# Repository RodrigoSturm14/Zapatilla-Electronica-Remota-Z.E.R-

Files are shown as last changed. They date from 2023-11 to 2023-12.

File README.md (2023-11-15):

#  Zapatilla Electrónica Remota (Z.E.R) ⚡🏠
zer_3

# Descripción del proyecto
Este repositorio se dedica a documentar y recopilar el desarrollo de **Z.E.R**; un proyecto de automatizacion IoT desarrollado por Montial Octavio, Pierini Franco, Vallone Fabrizio, Sturm Rodrigo y Zuñiga Juan Jose.

Z.E.R es una zapatilla eléctrica que fue diseñada para activar y desactivar sus tomacorrientes inalámbricamente mediante nuestra aplicación móvil a través del uso de comunicación MQTT.
Decidimos implementar el protocolo de comunicacion MQTT debido a su sensillo uso y accecible conectividad WiFi con el microcontrolador ESP32.
Gracias a este proyecto, ampliamos nuestro conocimiento en diferentes areas como en el **desarrollo de Hardware**, **diseño de PCBs**, **desarrollo de Software (JavaScript - C++)** y **diseño 3D (SolidWork)**.

# Caracteristicas de Z.E.R
* **Microcontrolador ESP32** para hacer posible la conectividad IoT y un alto nivel de procesamiento.
* **Protocolo de comunicación MQTT** para la transmisión de datos a tiempo real.
* **Aplicación móvil** para una interfaz gráfica de usuario sencilla y accesible.
*  **Aprovisionamiento WiFi** para la conexión automática a redes WiFi.
* **Almacenamiento no volátil (NVS)** para guardar información temporalmente en la memoria flash del microcontrolador.
* **Sistema embebido unificado** para mayor ahorro de espacio y material.

#  Estructura del Repositorio
* **/Software**, se hayan las carpetas y los archivos de la programación móvil y del sistema embebido.
* **/Hardware**, se haya los recursos para observar el progreso del diseño del PCB.
* **/Diseño 3D**, se encuentran los archivos .STL  utilizados en el proyecto.

# Archivos Multimedia

## Fotos
### Aplicacion Movil

Aqui se muestra la estructura de la app. En la seccion superior puede verse el nombre del dispositivo, mientras que en el resto de la pantalla se situa la informacion de los diferentes tomas. Se tienen los siguientes elementos para controlar cada uno de los tomacorriente: 

* **Botones de encender y apagar**
* **Tabla indicativa del estado del toma** (Su color y mensaje cambia depende el estado).



### Diagramas de conexion con el broker

En este diagrama se ven las conexiones entre el broker y los nodos de la aplicacion movil y el microcontrolador. El broker MQTT es un intermediario en la comunicacion entre la aplicacion movil y el ESP32. Para que este protocolo funcione, ambas partes deben estar conectadas a una red WiFi.

zer_4

### Interfaz grafica de conexiones en el broker

En esta imagen se ven representadas las conexiones que se realizan al usar el proyecto. El broker [Shiftr](https://www.shiftr.io/) permite ver un diagrama de conexiones a tiempo real de los clientes y los topicos. Por un lado, el "esp32-client" representa al microcontrolador de la zapatilla, el cual se encarga de recibir la informacion enviada por parte de la app. Esta ultima se ve en el otro extremo de la conexion. Por ultimo, se encuentran los "topicos" en donde se almacenan los mensajes enviados desde la app. Estos serian los tomas, y pueden adoptar un mensaje de "encendido" o "apagado".



### Placa Master 

En esta imagen se puede observar la placa principal del proyecto, la cual cumple el rol de recibir y confirmar este recibimiento los datos provenientes del broquer mqtt y encender o no cada uno de los tomas en consecuencia.
Principalmente está conformada por:
* **El microcontrolador Esp32:** Encargado de la comunicación con el broker mqtt y el proceso lógico en consecuencia
* **Los Relay:** Principales responsables del encendido y/o apagado de los tomas del proyecto.

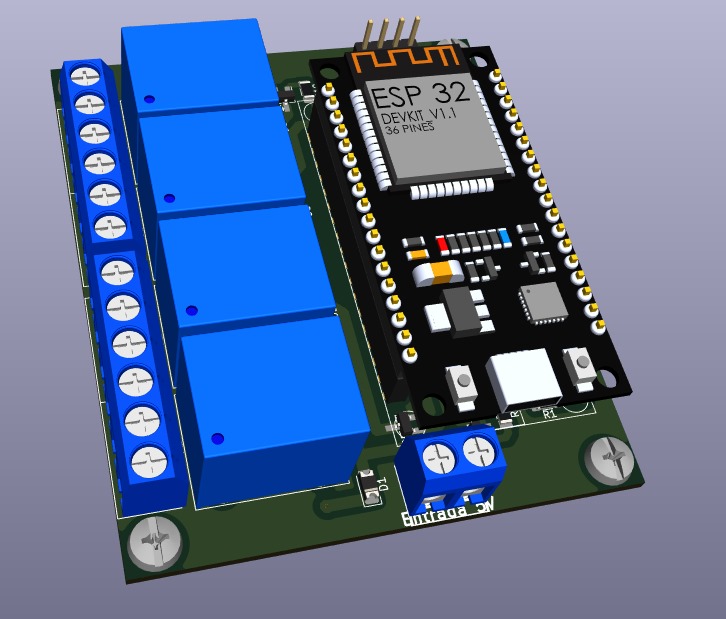
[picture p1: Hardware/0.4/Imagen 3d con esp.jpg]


### Placa de Periféricos:

En esta imagen se puede observar la placa secundaria del proyecto, la cual cumple el rol de mostrarle al usuario de forma visual el estado de conexión del dispositivo y una ruta de fácil acceso para poder reconfigurar este (conectar a una nueva red wifi). 
Principalmente está conformada por:
* **LEDs:** Quienes se encargan de mostrar si el dispositivo está conectado al Wifi, y de ser así, también otro para el caso del broquer mqtt.
* **Pulsador:** Perimite entrar al estado de configuración de Wifi en el caso de que este no pueda conectarse o de cambiar de ubicación el dispositivo.

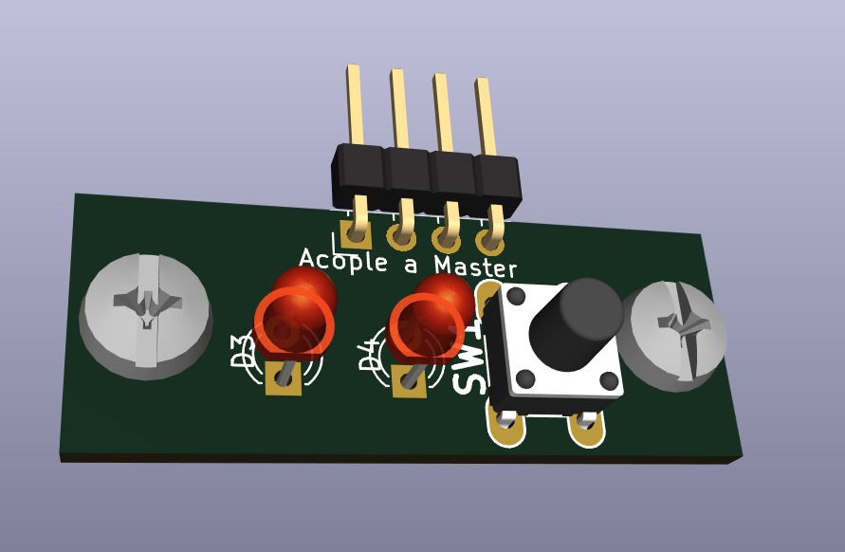
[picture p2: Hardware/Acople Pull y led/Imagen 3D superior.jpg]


## Videos
zer_video_img

[Video](https://drive.google.com/file/d/11wxJRINLuGf1xzWTfpv2VvfbYe2Eymw4/view?usp=sharing)

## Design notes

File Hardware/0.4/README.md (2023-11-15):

# Placa Master

En esta imagen se puede observar la placa principal del proyecto, la cual cumple el rol de recibir y confirmar este recibimiento los datos provenientes del broquer mqtt y encender o no cada uno de los tomas en consecuencia.
Principalmente está conformada por:
* **El microcontrolador Esp32:** Encargado de la comunicación con el broker mqtt y el proceso lógico en consecuencia.
* **Los Relay:** Principales responsables del encendido y/o apagado de los tomas del proyecto.



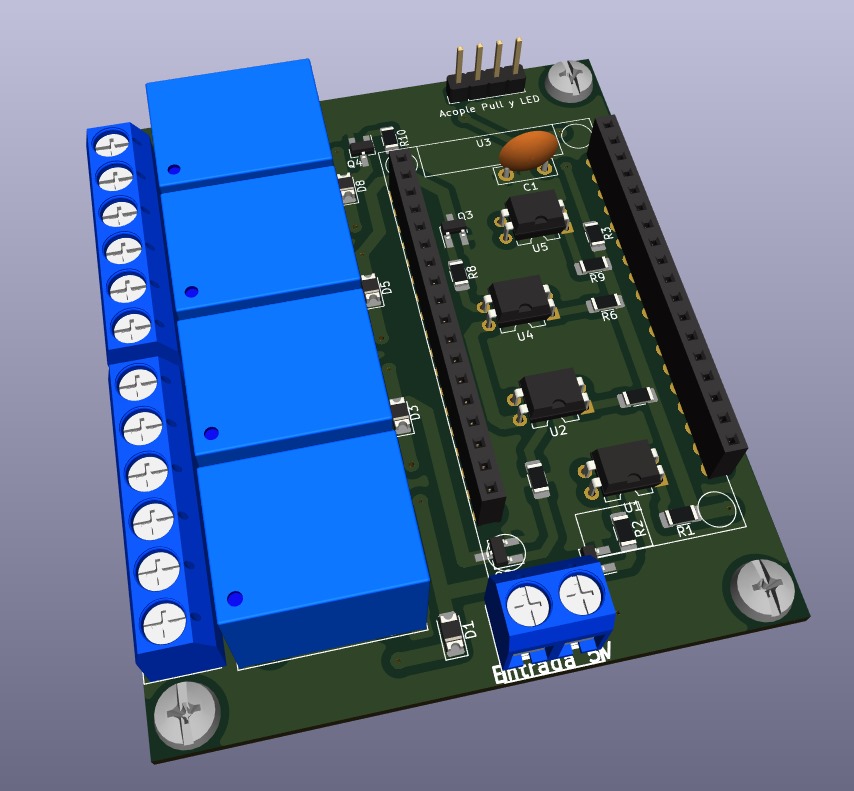
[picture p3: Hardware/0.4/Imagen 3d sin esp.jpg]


## Funcionamiento:

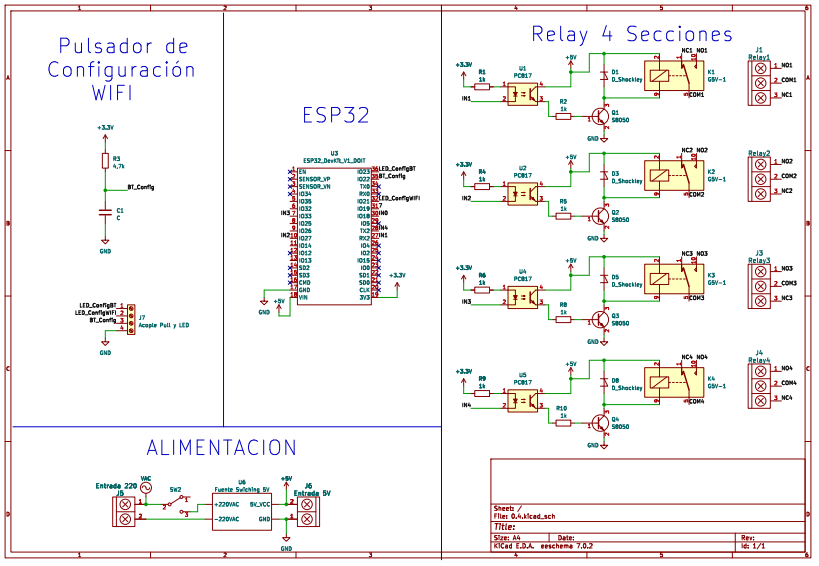
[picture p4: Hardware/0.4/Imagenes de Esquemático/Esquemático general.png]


Como se ve en el esquemático, la placa se separa en 4 partes:

### Esp32:

El cual permite la comunicacíon entre el broker mqtt y el la placa. Siendo el encargado de indicarle al resto de la placa las acciones a realizar.

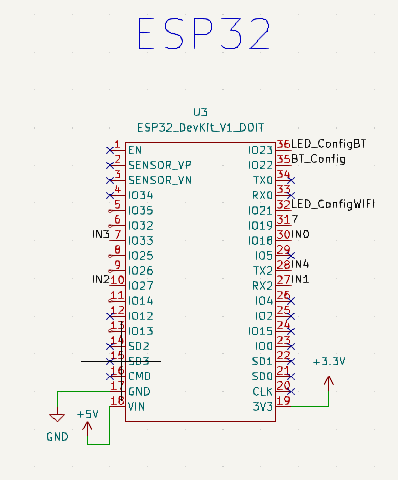
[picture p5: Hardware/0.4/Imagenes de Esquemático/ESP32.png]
esp


### Relay:

Aqui se utiliza la señal generada por el microcontrolador para accionar los relay y encender o apagar cada tomacorriete. 
Para esto se utilizan 2 componentes cruciales:
* **El octoacoplador:** Quien separa las tenciones del microcontrolador de las de actuación del relay.
* **El transistor:** Quien permite accionar el relay utilizando la señal del octoacoblador:

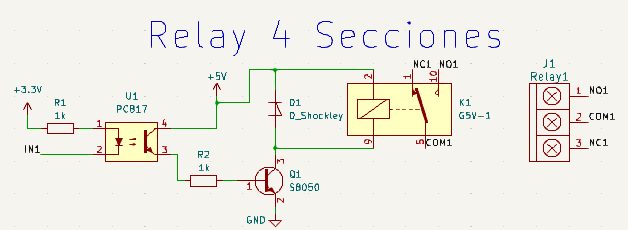
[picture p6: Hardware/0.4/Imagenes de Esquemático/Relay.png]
Relay


### Alimentación:
Aqui se utiliza una fuente switching genérica de 5v 700mA para poder alimentar el proyecto utilizando directamente la red doméstica.

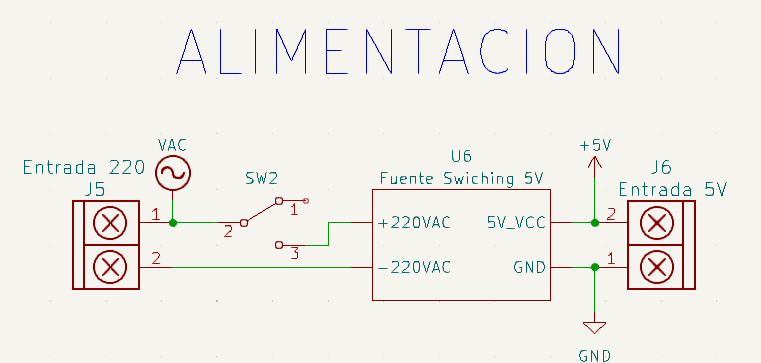
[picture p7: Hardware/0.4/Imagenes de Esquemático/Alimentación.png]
Alimen


### Pulsador de configuracion Wifi:
Aquí se ubica una coneccion la cual permitirá comunicar la placa master con el periferico restante.

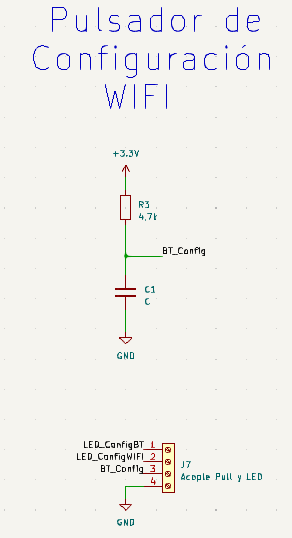
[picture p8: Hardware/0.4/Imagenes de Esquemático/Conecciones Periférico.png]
Pul


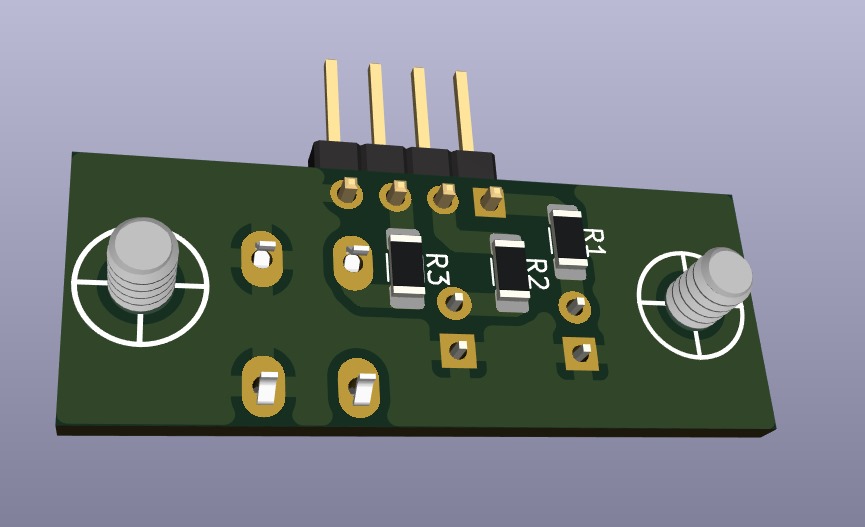
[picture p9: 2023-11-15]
Hardware/Acople Pull y led/Imagen 3D inferior.jpg

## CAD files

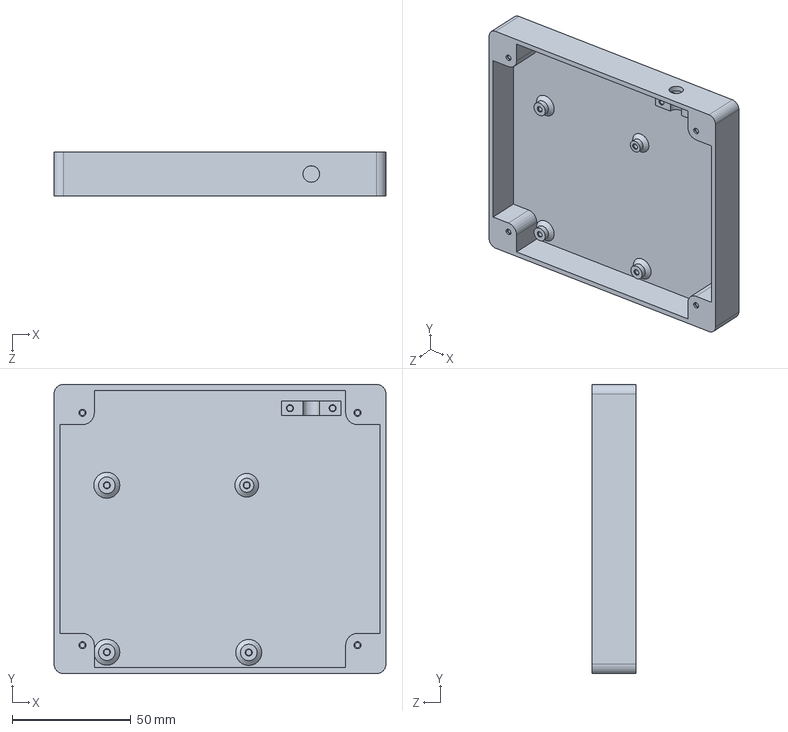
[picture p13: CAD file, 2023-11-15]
Diseño 3D/Base inferior.SLDPRT
140.0 x 122.0 x 18.5 mm

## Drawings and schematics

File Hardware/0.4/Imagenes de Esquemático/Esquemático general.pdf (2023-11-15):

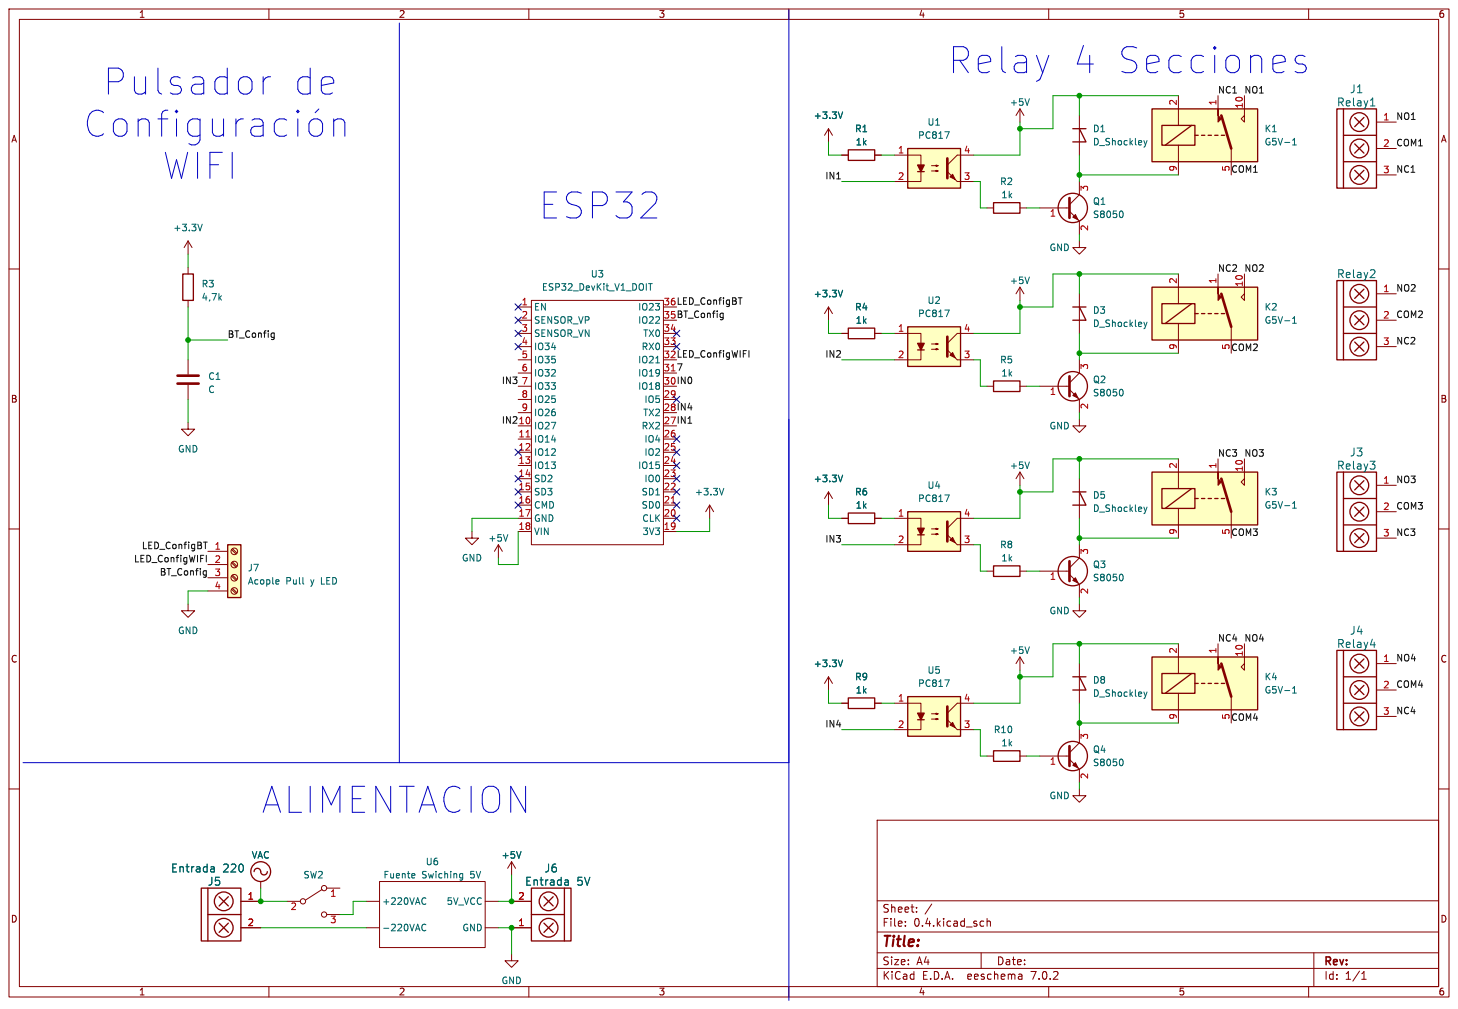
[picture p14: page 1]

Relay 4 Secciones Pulsador de
WIFI

Id: 1/1 Title: File: 0.4.kicad_sch Sheet: /

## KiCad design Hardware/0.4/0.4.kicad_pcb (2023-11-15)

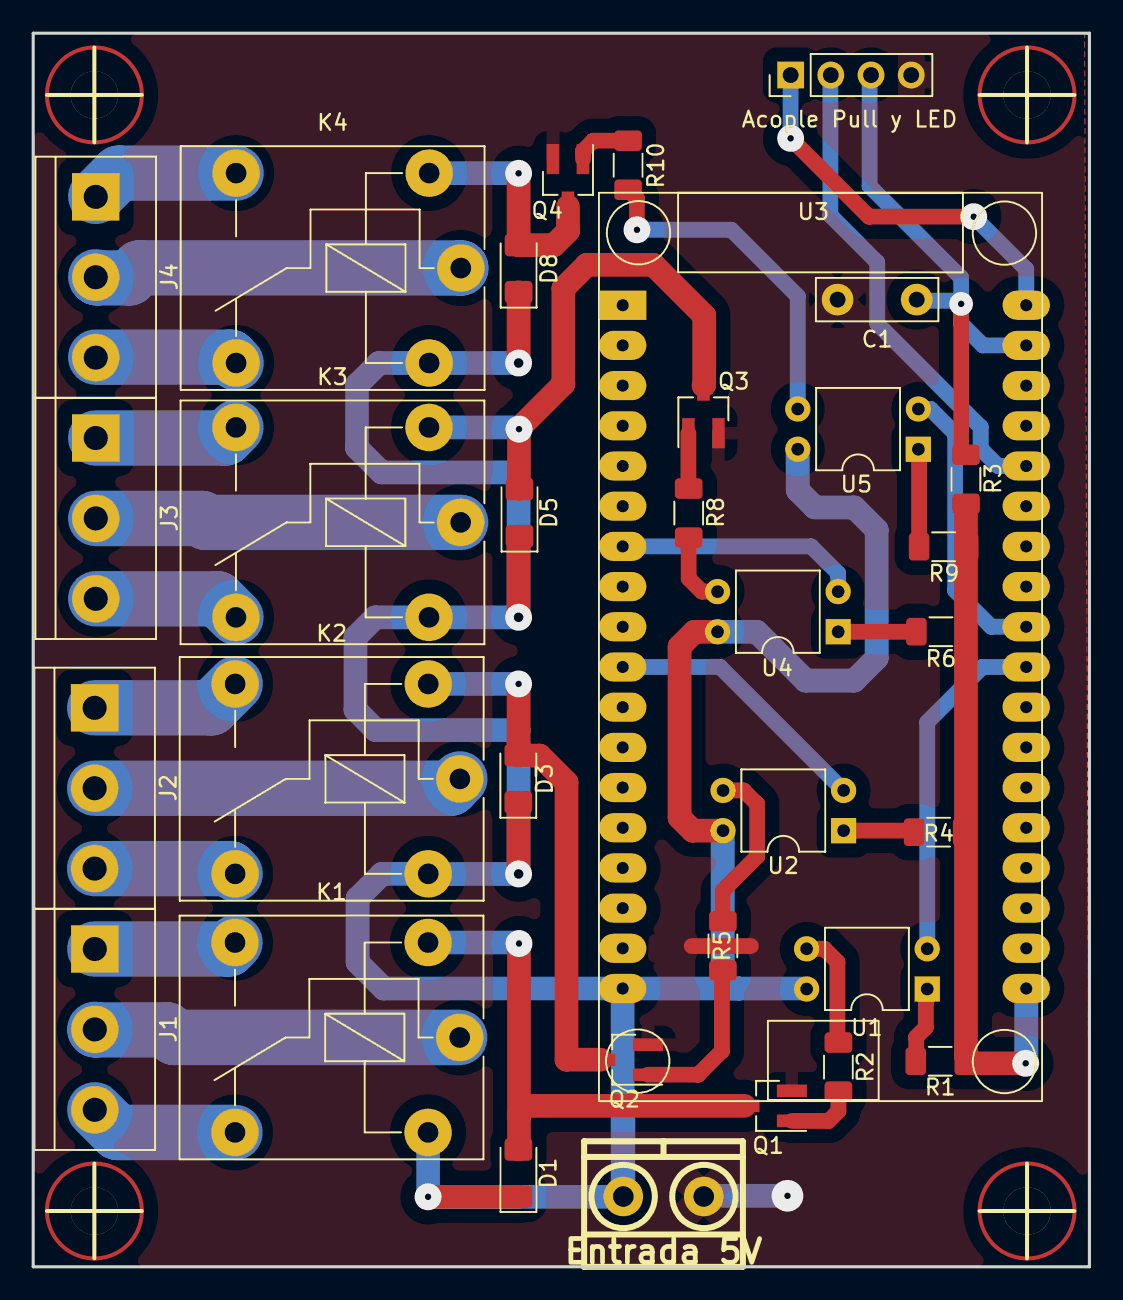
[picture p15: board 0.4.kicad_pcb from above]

Board: 2 copper layers, 66.7 x 78.0 mm, 37 parts (0 on the bottom side), 38 nets.

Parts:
C1: C; C_Disc_D7.5mm_W2.5mm_P5.00mm
D1, D3, D5, D8: D_Shockley; D_1206_3216Metric_Pad1.42x1.75mm_HandSolder
J1: Relay1; TerminalBlock_bornier-3_P5.08mm
J2: Relay2; TerminalBlock_bornier-3_P5.08mm
J3: Relay3; TerminalBlock_bornier-3_P5.08mm
J4: Relay4; TerminalBlock_bornier-3_P5.08mm
J6: Entrada 5V; BORNERA2_AZUL
J7: Acople Pull y LED; PinHeader_1x04_P2.54mm_Vertical
K1, K2, K3, K4: G5V-1; Relay_SPDT_Finder_36.11
Q1, Q2, Q3, Q4: S8050; SOT-23_Handsoldering
R1, R2, R4, R5, R6, R8, R9, R10: 1k; R_1206_3216Metric_Pad1.30x1.75mm_HandSolder
R3: 4,7k; R_1206_3216Metric_Pad1.30x1.75mm_HandSolder
U1, U2, U4, U5: PC817; DIP-4_W7.62mm
U3: ESP32_DevKit_V1_DOIT; ESP32_Devkit_V1_36pin
hole_3mm, hole_3mm#2, hole_3mm#3, hole_3mm#4: VAL**; hole_3mm

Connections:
+3V3: R1.1, R3.1, R4.1, R6.1, R9.1, U3.19 (3V3)
+5V: D1.1 (K), D3.1 (K), D5.1 (K), D8.1 (K), J6.2, K1.2, K2.2, K3.2, K4.2, U1.4, U2.4, U3.18 (VIN), U4.4, U5.4
/BT_Config: C1.1, J7.3, R3.2, U3.35 (IO22)
/COM1: J1.2, K1.5
/COM2: J2.2, K2.5
/COM3: J3.2, K3.5
/COM4: J4.2, K4.5
/IN1: U1.2, U3.27 (RX2)
/IN2: U2.2, U3.10 (IO27)
/IN3: U3.7 (IO33), U4.2
/IN4: U3.28 (TX2), U5.2
/LED_ConfigBT: J7.1, U3.36 (IO23)
/LED_ConfigWIFI: J7.2, U3.32 (IO21)
/NC1: J1.3, K1.1
/NC2: J2.3, K2.1
/NC3: J3.3, K3.1
/NC4: J4.3, K4.1
/NO1: J1.1, K1.10
/NO2: J2.1, K2.10
/NO3: J3.1, K3.10
/NO4: J4.1, K4.10
GND: C1.2, J6.1, J7.4, Q1.2 (E), Q2.2 (E), Q3.2 (E), Q4.2 (E), U3.17 (GND)
unnamed: D1.2 (A), K1.9, Q1.3 (C)
unnamed: D3.2 (A), K2.9, Q2.3 (C)
unnamed: D5.2 (A), K3.9, Q3.3 (C)
unnamed: D8.2 (A), K4.9, Q4.3 (C)
unnamed: Q1.1 (B), R2.2
unnamed: Q2.1 (B), R5.2
unnamed: Q3.1 (B), R8.2
unnamed: Q4.1 (B), R10.2
unnamed: R1.2, U1.1
unnamed: R2.1, U1.3
unnamed: R4.2, U2.1
unnamed: R5.1, U2.3
unnamed: R6.2, U4.1
unnamed: R8.1, U4.3
unnamed: R9.2, U5.1
unnamed: R10.1, U5.3

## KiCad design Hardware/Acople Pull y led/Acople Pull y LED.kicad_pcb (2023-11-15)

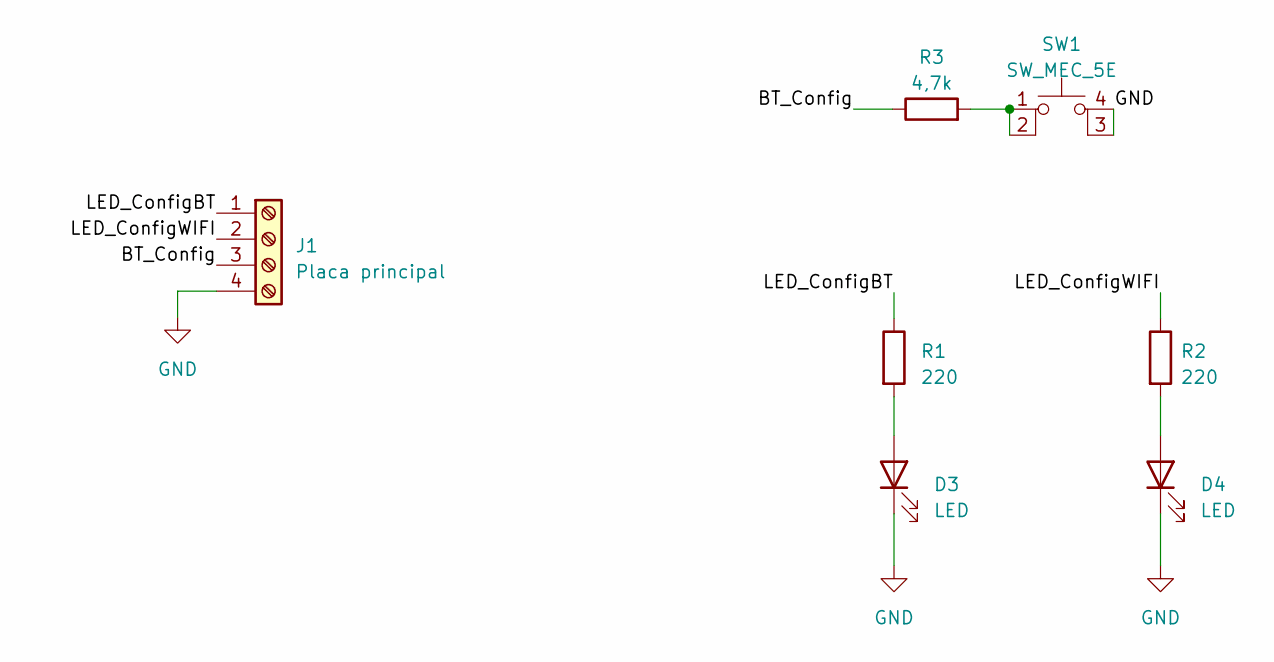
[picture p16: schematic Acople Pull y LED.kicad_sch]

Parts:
D3, D4: LED; LED_D3.0mm
J1: Placa principal; PinHeader_1x04_P2.54mm_Horizontal
R1, R2: 220; R_1206_3216Metric_Pad1.30x1.75mm_HandSolder
R3: 4,7k; R_1206_3216Metric_Pad1.30x1.75mm_HandSolder
SW1: SW_MEC_5E; Pulsador_TH_4

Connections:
/BT_Config: J1.3, R3.1
/LED_ConfigBT: J1.1, R1.1
/LED_ConfigWIFI: J1.2, R2.1
GND: D3.1 (K), D4.1 (K), J1.4, SW1.3 (K), SW1.4 (A)
unnamed: D3.2 (A), R1.2
unnamed: D4.2 (A), R2.2
unnamed: R3.2, SW1.1, SW1.2

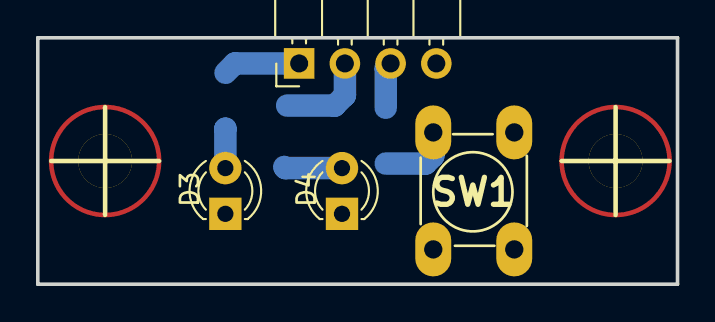
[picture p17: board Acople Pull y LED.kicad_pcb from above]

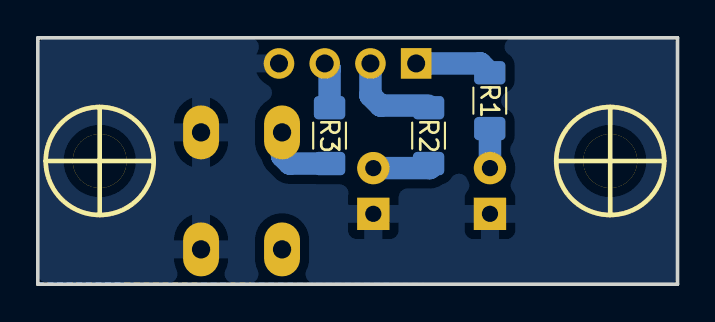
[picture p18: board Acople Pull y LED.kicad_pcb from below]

Board: 2 copper layers, 35.5 x 13.7 mm, 9 parts (3 on the bottom side), 7 nets.

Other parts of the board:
hole_3mm, hole_3mm#2: VAL**; hole_3mm

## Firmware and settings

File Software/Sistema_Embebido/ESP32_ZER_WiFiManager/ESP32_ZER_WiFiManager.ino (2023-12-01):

#include <Arduino.h>
#include <WiFi.h>
#include <ESPAsyncWebServer.h>
#include <AsyncTCP.h>
#include <PubSubClient.h>
#include "SPIFFS.h"

// ---------  Depuracion  ---------
#define DEBUG 1  // Cambiar el 0 por un 1 si se hacen prueb  as con el esp conectado al puerto serial.

// ---------  Componentes OUTPUT & INPUT de Control  ---------
#define CANT_OUTPUT 7
#define PIN_BOTON 22
#define PIN_LED_V 18
#define PIN_LED_R 21
#define PIN_LED_ESP 2
#define PIN_RELAY_1 16
#define PIN_RELAY_2 27
#define PIN_RELAY_3 33
#define PIN_RELAY_4 17
bool button_state;

int pines_output[CANT_OUTPUT] = { PIN_RELAY_1, PIN_RELAY_2, PIN_RELAY_3, PIN_RELAY_4, PIN_LED_V, PIN_LED_R, PIN_LED_ESP };

// ---------  WiFi & Broker MQTT  ---------
WiFiClient espClient;                        // Definir espClient como un objeto de la clase WiFiClient. 
PubSubClient client(espClient);              // Definir espClient como objeto de la clase PubSubClient.
const char *mqtt_broker = "";                // Direccion del broker (SHIFTR, EMQX U OTRO BROKER). E.g.: broker.emqx.io
const char *mqtt_username = "";              // Username para autenticacion.
const char *mqtt_password = "";              // Password para autenticacion.
const int mqtt_port = 1883;                  // Puerto MQTT sobre TCP.
bool wifi_state;
int PAYLOADINT;

// Create AsyncWebServer object on port 80
AsyncWebServer server(80);

// Search for parameter in HTTP POST request
const char* PARAM_INPUT_1 = "ssid";
const char* PARAM_INPUT_2 = "pass";
const char* PARAM_INPUT_3 = "ip";
const char* PARAM_INPUT_4 = "gateway";

//Variables to save values from HTML form
String ssid;
String pass;
String ip;
String gateway;

// File paths to save input values permanently
const char* ssidPath = "/ssid.txt";
const char* passPath = "/pass.txt";
const char* ipPath = "/ip.txt";
const char* gatewayPath = "/gateway.txt";

IPAddress localIP;
//IPAddress localIP(192, 168, 1, 200); // hardcoded

// Set your Gateway IP address
IPAddress localGateway;
//IPAddress localGateway(192, 168, 1, 1); //hardcoded
IPAddress subnet(255, 255, 0, 0);

// Timer variables
unsigned long previousMillis = 0;
const long interval = 10000;  // interval to wait for Wi-Fi connection (milliseconds)

// --- Funcion Iniciar SPIFFS ---
void initSPIFFS() {
  if (!SPIFFS.begin(true)) {
    if (DEBUG) Serial.println("An error has occurred while mounting SPIFFS");
  }
  if (DEBUG) Serial.println("SPIFFS mounted successfully");
}

// --- Funcion Leer archivo SPIFFS ---
String readFile(fs::FS& fs, const char* path) {
  if (DEBUG) Serial.printf("Reading file: %s\r\n", path);

  File file = fs.open(path);
  if (!file || file.isDirectory()) {
    if (DEBUG) Serial.println("- failed to open file for reading");
    return String();
  }

  String fileContent;
  while (file.available()) {
    fileContent = file.readStringUntil('\n');
    break;
  }
  return fileContent;
}

// --- Funcion Escribir en archivo SPIFFS ---
void writeFile(fs::FS& fs, const char* path, const char* message) {
  if (DEBUG) Serial.printf("Writing file: %s\r\n", path);

  File file = fs.open(path, FILE_WRITE);
  if (!file) {
    if (DEBUG) Serial.println("- failed to open file for writing");
    return;
  }
  if (file.print(message)) {
    if (DEBUG) Serial.println("- file written");
  } else {
    if (DEBUG) Serial.println("- write failed");
  }
}

// --- Funcion Iniciar conexion red WiFi ---
bool initWiFi() {
  digitalWrite(PIN_LED_R, HIGH);
  delay(500);
  if (ssid == "" || ip == "") {
    if (DEBUG) Serial.println("Undefined SSID or IP address.");
    return false;
  }

  WiFi.begin(ssid.c_str(), pass.c_str());
  if (DEBUG) Serial.println("Connecting to WiFi...");

  unsigned long currentMillis = millis();
  previousMillis = currentMillis;

  while (WiFi.status() != WL_CONNECTED) {
    currentMillis = millis();
    if (currentMillis - previousMillis >= interval) {
      if (DEBUG)Serial.println("Failed to connect.");
      return false;
    }
  }

  if (DEBUG) Serial.println(WiFi.localIP());
  digitalWrite(PIN_LED_R, LOW);
  delay(500);
  return true;
}

// --- Funcion Iniciar conexion broker MQTT ---
void initMQTT(String mqtt_url_broker, int mqtt_puerto) {

  if (WiFi.status() == WL_CONNECTED) {
    if (DEBUG) Serial.println("Conectado a WiFi network");  // Si el ESP logro conectarse a la red WiFi, intntara conectarse al broker MQTT.

    client.setServer(mqtt_broker, mqtt_port);
    client.setCallback(callback);

    while (!client.connected()) {
      
      digitalWrite(PIN_LED_R, HIGH);
      delay(500);
      
      String client_id = "esp32-client-";
      client_id += String(WiFi.macAddress());
      if (DEBUG) Serial.printf("The client ------ %s ------ connects to the public mqtt broker\n", client_id.c_str());  // here the macAddress of the esp32 (which is a unique identifier for the esp32) is printed in the string variable client_id. then client_id is passed to a char arrays with the function c_str().


      if (client.connect(client_id.c_str(), mqtt_username, mqtt_password)) {  // here the esp32 will try to connect with the broker
        if (DEBUG) Serial.println("Public emqx mqtt broker connected");
      } else {
        if (DEBUG) {
          Serial.print("failed with state ");
          Serial.print(client.state());
        }
        digitalWrite(PIN_LED_R, LOW);
        delay(2000);
      }
    }

    // --- Funciones Publish & Subscribe ---
    client.publish("TOMA1", "Hola Shiftr y Celular soy ESP32 :] , escribiendo en TOMA1.");
    client.subscribe("TOMA1");
    client.subscribe("TOMA2");
    client.subscribe("TOMA3");
    client.subscribe("TOMA4");
    delay(1000);
    digitalWrite(PIN_LED_V, HIGH);
    digitalWrite(PIN_LED_R, LOW);
  }
}

// --- Funcion Callback MQTT ---
void callback(char *topic, byte *payload, unsigned int length) {  // here the message from the broker is trasmitted to the esp32 with the variable payload

  if (strcmp(topic, "TOMA1") == 0) {
    digitalWrite(PIN_LED_ESP, HIGH);
    delay(500);
    digitalWrite(PIN_LED_ESP, LOW);
    if (DEBUG) {
      Serial.print("Message arrived in topic: ");
      Serial.println(topic);
      Serial.print("Message: ");
    }
    for (int i = 0; i < length; i++) {
      if (DEBUG) Serial.print((char)payload[i]);
    }
    char payload_string[length + 1];
    memcpy(payload_string, payload, length);
    payload_string[length] = '\0'; // se le agrega un NULL TERMINATED al final de la string, ya que de esa forma el programa sabe en donde termina la string.
    PAYLOADINT = atoi(payload_string);
    if (DEBUG) {
      Serial.println();
      Serial.print("Payload as a integer:");
      Serial.print(PAYLOADINT);
      Serial.println();
      Serial.println("-----------------------");
    }

    if (PAYLOADINT == 1) {
      digitalWrite(PIN_RELAY_1, LOW);  // PRENDER RELAY 1
      client.publish("NOTIFICACION", "TOMA 1 ACTIVADO - ESP32");
    } else if (PAYLOADINT == 0) {
      digitalWrite(PIN_RELAY_1, HIGH);  // APAGAR RELAY 1
      client.publish("NOTIFICACION", "TOMA 1 DESACTIVADO - ESP32");
    }
  }

  else if (strcmp(topic, "TOMA2") == 0) {
    digitalWrite(PIN_LED_ESP, HIGH);
    delay(500);
    digitalWrite(PIN_LED_ESP, LOW);
    if (DEBUG) {
      Serial.print("Message arrived in topic: ");
      Serial.println(topic);
      Serial.print("Message:");
    }
    for (int i = 0; i < length; i++) {
      if (DEBUG) Serial.print((char)payload[i]);
    }
    char payload_string[length + 1];
    memcpy(payload_string, payload, length);
    payload_string[length] = '\0';
    PAYLOADINT = atoi(payload_string);
    if (DEBUG) {
      Serial.println();
      Serial.print("Payload as a integer:");
      Serial.print(PAYLOADINT);
      Serial.println();
      Serial.println("-----------------------");
    }

    if (PAYLOADINT == 1) {
      digitalWrite(PIN_RELAY_2, LOW);  // PRENDER RELAY 2.
      client.publish("NOTIFICACION", "TOMA 2 ACTIVADO - ESP32");
    } else if (PAYLOADINT == 0) {
      digitalWrite(PIN_RELAY_2, HIGH);  // APAGAR RELAY 2.
      client.publish("NOTIFICACION", "TOMA 2 DESACTIVADO - ESP32");
    }
  }

  else if (strcmp(topic, "TOMA3") == 0) {
    digitalWrite(PIN_LED_ESP, HIGH);
    delay(500);
    digitalWrite(PIN_LED_ESP, LOW);
    if (DEBUG) {
      Serial.print("Message arrived in topic: ");
      Serial.println(topic);
      Serial.print("Message:");
    }
    for (int i = 0; i < length; i++) {
      if (DEBUG) Serial.print((char)payload[i]);
    }
    char payload_string[length + 1];
    memcpy(payload_string, payload, length);
    payload_string[length] = '\0';
    PAYLOADINT = atoi(payload_string);
    if (DEBUG) {
      Serial.println();
      Serial.print("Payload as a integer:");
      Serial.print(PAYLOADINT);
      Serial.println();
      Serial.println("-----------------------");
    }

    if (PAYLOADINT == 1) {
      digitalWrite(PIN_RELAY_3, LOW);  // PRENDER RELAY 3.
      client.publish("NOTIFICACION", "TOMA 3 ACTIVADO - ESP32");
    } else if (PAYLOADINT == 0) {
      digitalWrite(PIN_RELAY_3, HIGH);  // APAGAR RELAY 3.
      client.publish("NOTIFICACION", "TOMA 3 DESACTIVADO - ESP32");
    }
  }

  else if (strcmp(topic, "TOMA4") == 0) {
    digitalWrite(PIN_LED_ESP, HIGH);
    delay(500);
    digitalWrite(PIN_LED_ESP, LOW);
    if (DEBUG) {
      Serial.print("Message arrived in topic: ");
      Serial.println(topic);
      Serial.print("Message:");
    }
    for (int i = 0; i < length; i++) {
      if (DEBUG) Serial.print((char)payload[i]);
    }
    char payload_string[length + 1];
    memcpy(payload_string, payload, length);
    payload_string[length] = '\0';
    PAYLOADINT = atoi(payload_string);
    if (DEBUG) {
      Serial.println();
      Serial.print("Payload as a integer:");
      Serial.print(PAYLOADINT);
      Serial.println();
      Serial.println("-----------------------");
    }

    if (PAYLOADINT == 1) {
      digitalWrite(PIN_RELAY_4, LOW);  // PRENDER RELAY 4.
      client.publish("NOTIFICACION", "TOMA 4 ACTIVADO - ESP32");
    } else if (PAYLOADINT == 0) {
      digitalWrite(PIN_RELAY_4, HIGH);  // APAGAR RELAY 4.
      client.publish("NOTIFICACION", "TOMA 4 DESACTIVADO - ESP32");
    }
  }
}

// --- Funcion Declaracion pines ---
void pinSetup() {
  pinMode(PIN_BOTON, INPUT);
  // declaracion de outputs
  for (int i = 0; i < CANT_OUTPUT; i++) {
    pinMode(pines_output[i], OUTPUT);
  }
  // deshabilitar relays
  for (int i = 0; i < 4; i++) {
    digitalWrite(pines_output[i], HIGH);
  }
  digitalWrite(PIN_LED_R, LOW);
}


void setup() {
  // Serial port for debugging purposes
  Serial.begin(115200);
  pinSetup();

  initSPIFFS();

  // Load values saved in SPIFFS
  ssid = readFile(SPIFFS, ssidPath);
  pass = readFile(SPIFFS, passPath);
  ip = readFile(SPIFFS, ipPath);
  gateway = readFile(SPIFFS, gatewayPath);
  if (DEBUG) {
    Serial.println(ssid);
    Serial.println(pass);
    Serial.println(ip);
    Serial.println(gateway);
  }
  
  wifi_state = initWiFi();

  if (wifi_state) {
    initMQTT(mqtt_broker, mqtt_port);

    while (digitalRead(PIN_BOTON) == 1 && WiFi.status() == WL_CONNECTED) {  // EL PROGRAMA VA ENTRAR Y REPETIR EL WHILE SIMPRE Y CUANDO NO SE ESTE PRESIONANDO EL BOTON Y EL ESP32 ESTE CONECTADO A UNA RED WIFI.
      client.loop();
    }
  }

  if (WiFi.status() == WL_CONNECTED) WiFi.disconnect(true);
  digitalWrite(PIN_LED_V, LOW);
  digitalWrite(PIN_LED_R, HIGH);

  // Connect to Wi-Fi network with SSID and password
  if (DEBUG)Serial.println("Setting AP (Access Point)");
  // NULL sets an open Access Point
  WiFi.softAP("ESP-WIFI-MANAGER", NULL);

  IPAddress IP = WiFi.softAPIP();
  if (DEBUG) {
    Serial.print("AP IP address: ");
    Serial.println(IP);
  }

  // Web Server Root URL
  server.on("/", HTTP_GET, [](AsyncWebServerRequest * request) {
    request->send(SPIFFS, "/wifimanager.html", "text/html");
  });

  server.serveStatic("/", SPIFFS, "/");

  server.on("/", HTTP_POST, [](AsyncWebServerRequest * request) {
    int params = request->params();
    for (int i = 0; i < params; i++) {
      AsyncWebParameter* p = request->getParam(i);
      if (p->isPost()) {
        // HTTP POST ssid value
        if (p->name() == PARAM_INPUT_1) {
          ssid = p->value().c_str();
          if (DEBUG) {
            Serial.print("SSID set to: ");
            Serial.println(ssid);
          }
          // Write file to save value
          writeFile(SPIFFS, ssidPath, ssid.c_str());
        }
        // HTTP POST pass value
        if (p->name() == PARAM_INPUT_2) {
          pass = p->value().c_str();
          if (DEBUG) {
            Serial.print("Password set to: ");
            Serial.println(pass);
          }
          // Write file to save value
          writeFile(SPIFFS, passPath, pass.c_str());
        }
        // HTTP POST ip value
        if (p->name() == PARAM_INPUT_3) {
          ip = p->value().c_str();
          if (DEBUG) {
            Serial.print("IP Address set to: ");
            Serial.println(ip);
          }
          // Write file to save value
          writeFile(SPIFFS, ipPath, ip.c_str());
        }
        // HTTP POST gateway value
        if (p->name() == PARAM_INPUT_4) {
          gateway = p->value().c_str();
          if (DEBUG) {
            Serial.print("Gateway set to: ");
            Serial.println(gateway);
          }
          // Write file to save value
          writeFile(SPIFFS, gatewayPath, gateway.c_str());
        }
        //Serial.printf("POST[%s]: %s\n", p->name().c_str(), p->value().c_str());
      }
    }
    request->send(200, "text/plain", "Done. ESP will restart, connect to your router and go to IP address: " + ip);
    delay(3000);
    ESP.restart();
  });
  server.begin();

}

void loop() {
}

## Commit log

2023-11-13 Agregue archivo programacion ESP32
2023-11-13 Agregue archivo HTML para aprovisionamiento WiFi
2023-11-13 Agregue archivo de estilos para WiFiManager
2023-11-13 Agregue link de video a README
2023-11-13 Agregue link de video a archivo README.md
2023-11-14 Se ha subido el codigo de la app.
2023-11-15 Subir Archivos de Hardware y Modelos 3D del proyecto
    [0.4.kicad_pcb, 0.4.kicad_sch, Acople Pull y LED.kicad_pcb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]
2023-11-15 Update README.md
    Agregando sección relacionada con el hardware
2023-11-15 Agregue foto principal de la zapatilla a README.md
2023-11-15 Agregue diagrama de conexiones a README.md
2023-11-15 Agregue descripcion de diagrama a README.md
2023-11-15 Subiendo README de hardware
2023-11-15 Subiendo imágenes esquemático master
    [0.4.kicad_sch]
2023-11-15 Update README.md
    Readme de placa master
